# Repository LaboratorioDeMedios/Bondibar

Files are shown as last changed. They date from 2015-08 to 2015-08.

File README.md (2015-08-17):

# Bondibar
Sendero's LED strip driver PCB

Sendero is a lighting system designed for artistic production (https://github.com/LaboratorioDeMedios/Sendero).

In this repository you will find the Eagle files for building the Bondibar PCB.

The Bondibar is a LED Strip driver using WS2801.

The Bondibar uses standard USB cables to daisychain data transmission, IRF520 high power transistors to power up up to 8 LED strips per PCB, and it can also daisychain power from one Bondibar to another.

The Bondibar was designed by Pablo Gindel (http://www.pablogindel.com) in 2013-2014.

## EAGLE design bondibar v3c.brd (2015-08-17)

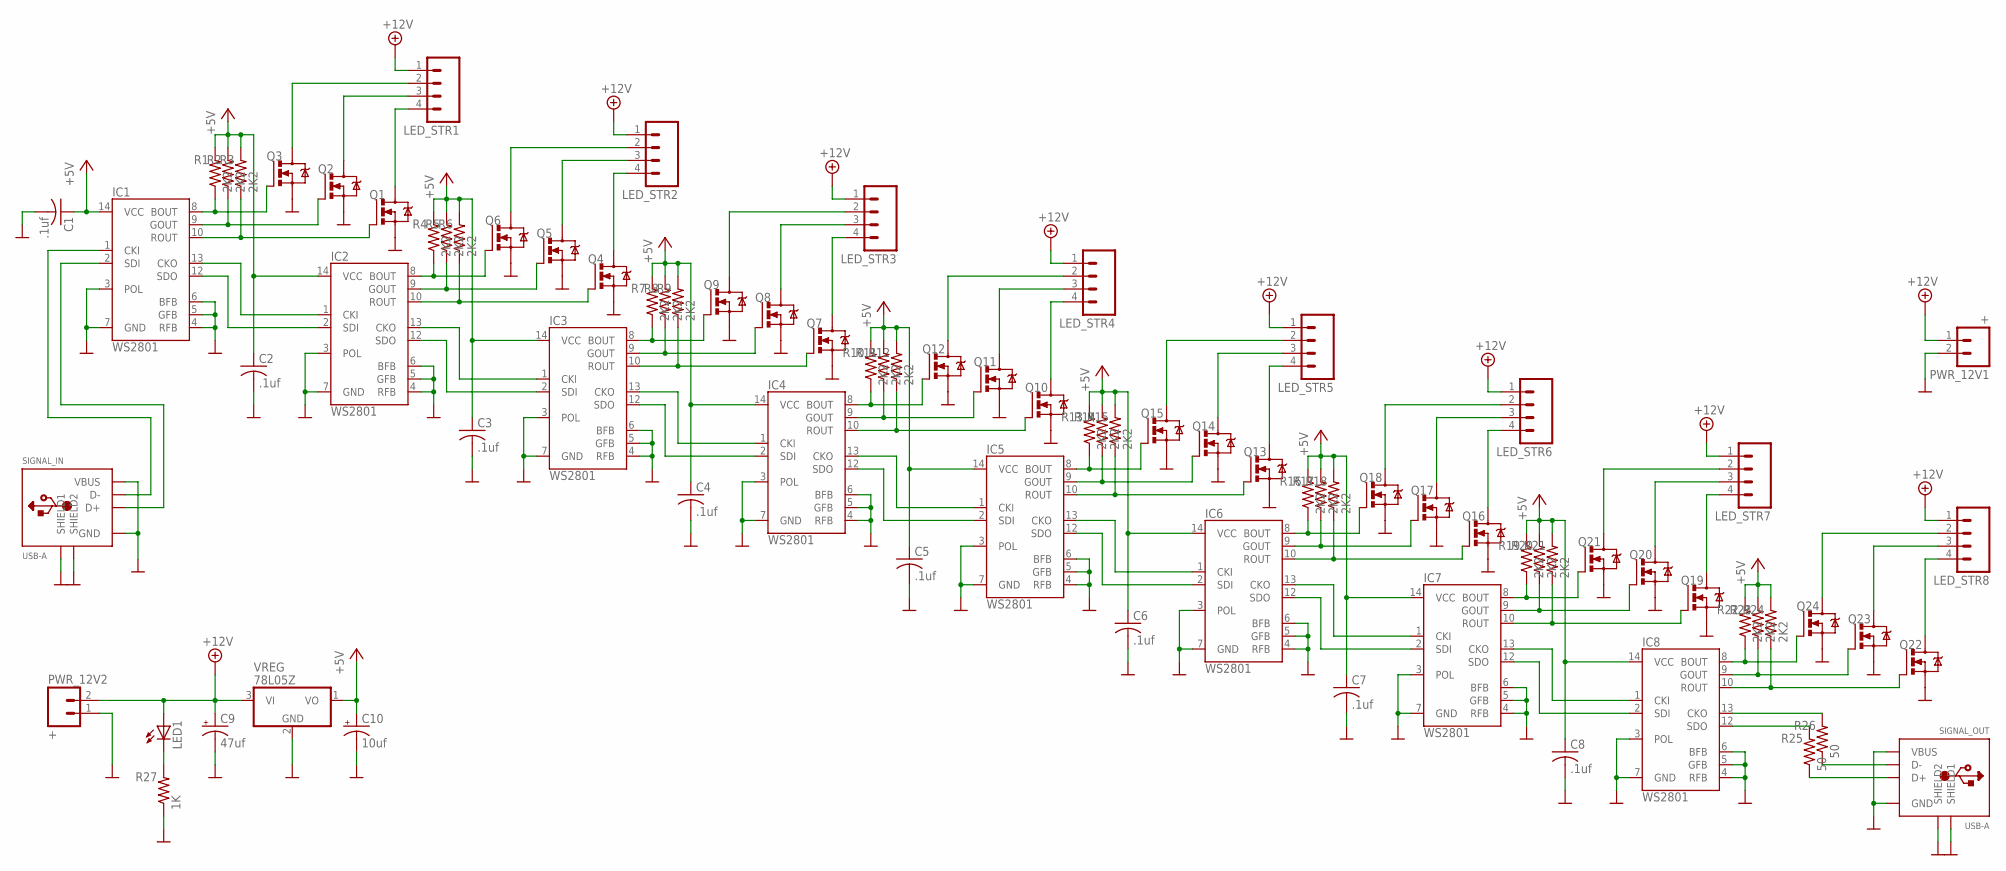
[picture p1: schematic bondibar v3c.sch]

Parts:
C1, C2, C3, C4, C5, C6, C7, C8: .1uf; C025-024X044
C9: 47uf; E2,5-6E
C10: 10uf; E2,5-6E
IC1, IC2, IC3, IC4, IC5, IC6, IC7, IC8: WS2801; SOP-14
LED1: LED3MM
LED_STR1, LED_STR2, LED_STR3, LED_STR4, LED_STR5, LED_STR6, LED_STR7, LED_STR8: M04PTH; 1X04
PWR_12V1, PWR_12V2: +; SCREWTERMINAL-5MM-2
Q1, Q2, Q3, Q4, Q5, Q6, Q7, Q8, Q9, Q10, Q11, Q12, Q13, Q14, Q15, Q16, Q17, Q18, Q19, Q20, Q21, Q22, Q23, Q24: IRF520; TO220BV
R1, R2, R3, R4, R5, R6, R7, R8, R9, R10, R11, R12, R13, R14, R15, R16, R17, R18, R19, R20, R21, R22, R23, R24: 2K2; 0204V
R25, R26: 50; 0204V
R27: 1K; 0204V
SIGNAL_IN: USB-A; USB_HOST-PTH
SIGNAL_OUT: USB-A; USB_HOST-PTH
VREG: 78L05Z; TO92

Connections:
+5V: C1.1, C2.1, C3.1, C4.1, C5.1, C6.1, C7.1, C8.1, C10.+, IC1.14 (VCC), IC2.14 (VCC), IC3.14 (VCC), IC4.14 (VCC), IC5.14 (VCC), IC6.14 (VCC), IC7.14 (VCC), IC8.14 (VCC), R1.2, R2.2, R3.2, R4.2, R5.2, R6.2, R7.2, R8.2, R9.2, R10.2, R11.2, R12.2, R13.2, R14.2, R15.2, R16.2, R17.2, R18.2, R19.2, R20.2, R21.2, R22.2, R23.2, R24.2, VREG.1 (VO)
+12V: C9.+, LED1.A, LED_STR1.1, LED_STR2.1, LED_STR3.1, LED_STR4.1, LED_STR5.1, LED_STR6.1, LED_STR7.1, LED_STR8.1, PWR_12V1.1, PWR_12V2.2, VREG.3 (VI)
DATA_IN: IC1.1 (CKI), SIGNAL_IN.D-
GND: C1.2, C2.2, C3.2, C4.2, C5.2, C6.2, C7.2, C8.2, C9.-, C10.-, IC1.3 (POL), IC1.4 (RFB), IC1.5 (GFB), IC1.6 (BFB), IC1.7 (GND), IC2.3 (POL), IC2.4 (RFB), IC2.5 (GFB), IC2.6 (BFB), IC2.7 (GND), IC3.3 (POL), IC3.4 (RFB), IC3.5 (GFB), IC3.6 (BFB), IC3.7 (GND), IC4.3 (POL), IC4.4 (RFB), IC4.5 (GFB), IC4.6 (BFB), IC4.7 (GND), IC5.3 (POL), IC5.4 (RFB), IC5.5 (GFB), IC5.6 (BFB), IC5.7 (GND), IC6.3 (POL), IC6.4 (RFB), IC6.5 (GFB), IC6.6 (BFB), IC6.7 (GND), IC7.3 (POL), IC7.4 (RFB), IC7.5 (GFB), IC7.6 (BFB), IC7.7 (GND), IC8.3 (POL), IC8.4 (RFB), IC8.5 (GFB), IC8.6 (BFB), IC8.7 (GND), PWR_12V1.2, PWR_12V2.1, Q1.S, Q2.S, Q3.S, Q4.S, Q5.S, Q6.S, Q7.S, Q8.S, Q9.S, Q10.S, Q11.S, Q12.S, Q13.S, Q14.S, Q15.S, Q16.S, Q17.S, Q18.S, Q19.S, Q20.S, Q21.S, Q22.S, Q23.S, Q24.S, R27.1, SIGNAL_IN.GND, SIGNAL_IN.S1 (SHIELD1), SIGNAL_IN.S2 (SHIELD2), SIGNAL_IN.VBUS, SIGNAL_OUT.GND, SIGNAL_OUT.S1 (SHIELD1), SIGNAL_OUT.S2 (SHIELD2), SIGNAL_OUT.VBUS, VREG.2 (GND)
unnamed: IC1.8 (BOUT), Q3.G, R1.1
unnamed: IC1.9 (GOUT), Q2.G, R2.1
unnamed: IC1.10 (ROUT), Q1.G, R3.1
unnamed: IC2.8 (BOUT), Q6.G, R4.1
unnamed: IC2.12 (SDO), IC3.2 (SDI)
unnamed: IC2.9 (GOUT), Q5.G, R5.1
unnamed: IC2.10 (ROUT), Q4.G, R6.1
unnamed: IC1.12 (SDO), IC2.2 (SDI)
unnamed: IC2.13 (CKO), IC3.1 (CKI)
unnamed: IC1.13 (CKO), IC2.1 (CKI)
unnamed: IC3.12 (SDO), IC4.2 (SDI)
unnamed: IC3.13 (CKO), IC4.1 (CKI)
unnamed: IC4.13 (CKO), IC5.1 (CKI)
unnamed: IC3.8 (BOUT), Q9.G, R7.1
unnamed: IC3.9 (GOUT), Q8.G, R8.1
unnamed: IC3.10 (ROUT), Q7.G, R9.1
unnamed: IC4.12 (SDO), IC5.2 (SDI)
unnamed: IC5.12 (SDO), IC6.2 (SDI)
unnamed: IC5.13 (CKO), IC6.1 (CKI)
unnamed: IC6.12 (SDO), IC7.2 (SDI)
unnamed: IC6.13 (CKO), IC7.1 (CKI)
unnamed: IC7.12 (SDO), IC8.2 (SDI)
unnamed: IC4.8 (BOUT), Q12.G, R10.1
unnamed: IC4.9 (GOUT), Q11.G, R11.1
unnamed: IC4.10 (ROUT), Q10.G, R12.1
unnamed: IC7.13 (CKO), IC8.1 (CKI)
unnamed: LED_STR1.4, Q1.D
unnamed: LED_STR1.3, Q2.D
unnamed: LED_STR1.2, Q3.D
unnamed: LED_STR4.3, Q11.D
unnamed: LED_STR4.4, Q10.D
unnamed: LED_STR2.4, Q4.D
unnamed: LED_STR2.3, Q5.D
unnamed: LED_STR2.2, Q6.D
unnamed: IC5.8 (BOUT), Q15.G, R13.1
unnamed: IC5.9 (GOUT), Q14.G, R14.1
unnamed: IC5.10 (ROUT), Q13.G, R15.1
unnamed: LED_STR3.2, Q9.D
unnamed: LED_STR3.3, Q8.D
unnamed: LED_STR3.4, Q7.D
unnamed: LED_STR4.2, Q12.D
unnamed: LED_STR5.2, Q15.D
unnamed: LED_STR5.3, Q14.D
unnamed: IC6.8 (BOUT), Q18.G, R16.1
unnamed: IC6.9 (GOUT), Q17.G, R17.1
unnamed: IC6.10 (ROUT), Q16.G, R18.1
unnamed: LED_STR5.4, Q13.D
unnamed: LED_STR6.2, Q18.D
unnamed: LED_STR6.3, Q17.D
unnamed: LED_STR6.4, Q16.D
unnamed: LED_STR7.2, Q21.D
unnamed: LED_STR7.3, Q20.D
unnamed: LED_STR7.4, Q19.D
unnamed: LED_STR8.2, Q24.D
unnamed: LED_STR8.3, Q23.D
unnamed: IC7.8 (BOUT), Q21.G, R19.1
unnamed: IC7.9 (GOUT), Q20.G, R20.1
unnamed: IC7.10 (ROUT), Q19.G, R21.1
unnamed: LED_STR8.4, Q22.D
unnamed: R26.1, SIGNAL_OUT.D-
unnamed: IC1.2 (SDI), SIGNAL_IN.D+
unnamed: IC8.12 (SDO), R25.2
unnamed: R25.1, SIGNAL_OUT.D+
unnamed: IC8.13 (CKO), R26.2
unnamed: IC8.8 (BOUT), Q24.G, R22.1
unnamed: IC8.9 (GOUT), Q23.G, R23.1
unnamed: IC8.10 (ROUT), Q22.G, R24.1
unnamed: LED1.K (C), R27.2

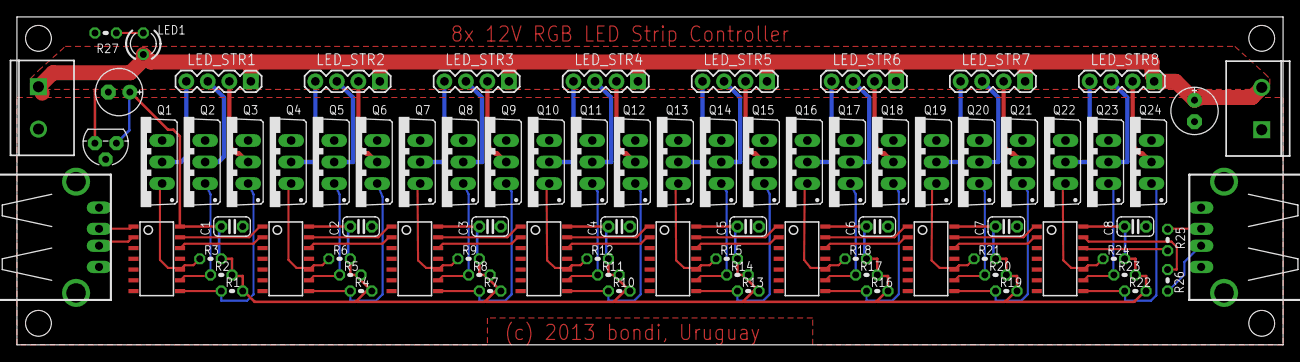
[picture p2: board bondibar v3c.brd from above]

Board: 2 copper layers, 149.5 x 38.7 mm, 87 parts (0 on the bottom side), 72 nets.

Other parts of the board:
U$56, U$57, U$58, U$59: STAND-OFF-TIGHT

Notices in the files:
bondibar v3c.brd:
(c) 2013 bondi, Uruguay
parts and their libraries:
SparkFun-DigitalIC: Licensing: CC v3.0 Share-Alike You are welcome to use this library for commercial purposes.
